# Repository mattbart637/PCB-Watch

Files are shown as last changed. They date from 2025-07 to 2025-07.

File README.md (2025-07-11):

# PCB Watch

<p style="text-align:center;">
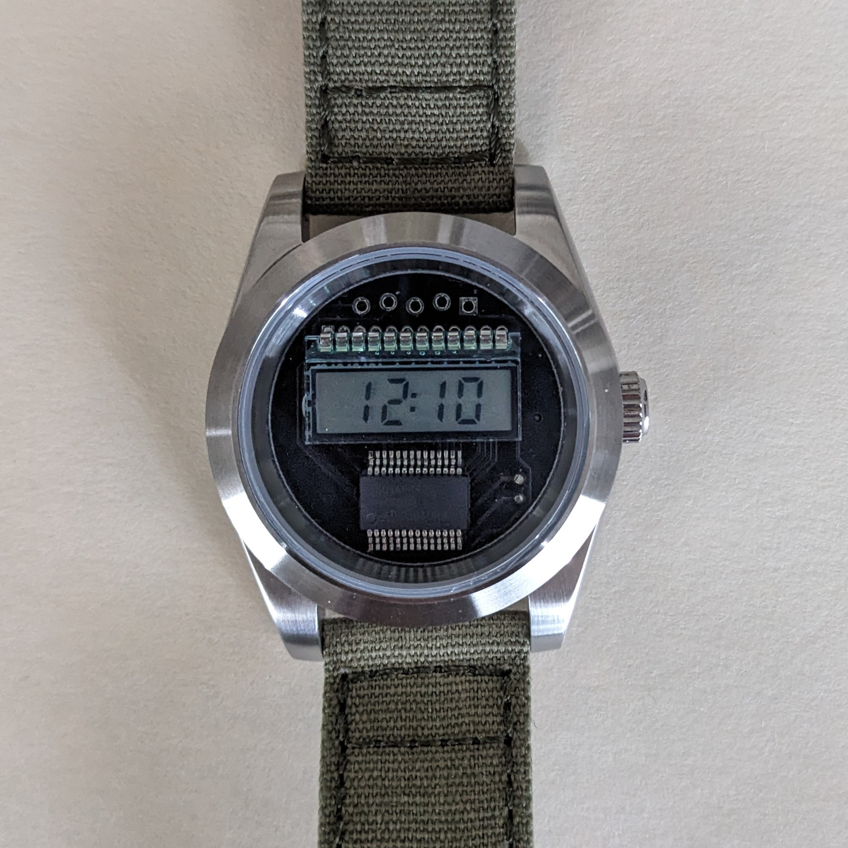
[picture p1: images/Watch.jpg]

</p>

A digital watch with a PIC16 and 4-digit segmented LCD display on a 2-layer PCB. It's my first microcontroller project outside the Arduino environment and the smallest SMT soldering I've done to date.

This build was heavily inspired by [Joe Sullivan's take](http://joesul.li/van/watch/) on a PIC16 watch. I loved finished look but didn't trust my soldering skills for the tiny hall-effect sensor or the daughter board it mounts on. Instead I simplified the interface to a single push-button. It makes the hardware simpler, but the firmware took a while to wrap my head around. 

I designed it for Seiko NH35 watch cases that accept 29mm dials, mostly because the NH35 has a strong modding community and there's plenty of aftermarket cases available. I got mine on AliExpress for under $20. A pair of 3D-printed spacers completes the build.

# Specs

| | |
| --- | --- |
| Dimensions | 29mm diameter, 7mm thick |
| Accuracy | 0.43 seconds/day, ~5 PPM |
| Current draw | 28.5µA @ 3V |
| Battery type | CR1220 |
| Runtime on 40mAh battery | ~58 days (estimate) |

# How to Use 

Once you insert a CR1220 battery it starts keeping time from 12:00.

1. Press and hold the button until Decimal Point 3 (DP3) lights up. Short press the button to change the minute.
2. Press and hold again and Decimal Point 1 (DP1) will light instead. Short press the button to change the hour.
3. Press and hold a final time until the decimal point turns off, setting the time.

<p style="text-align:center;">

</p>

# Photos

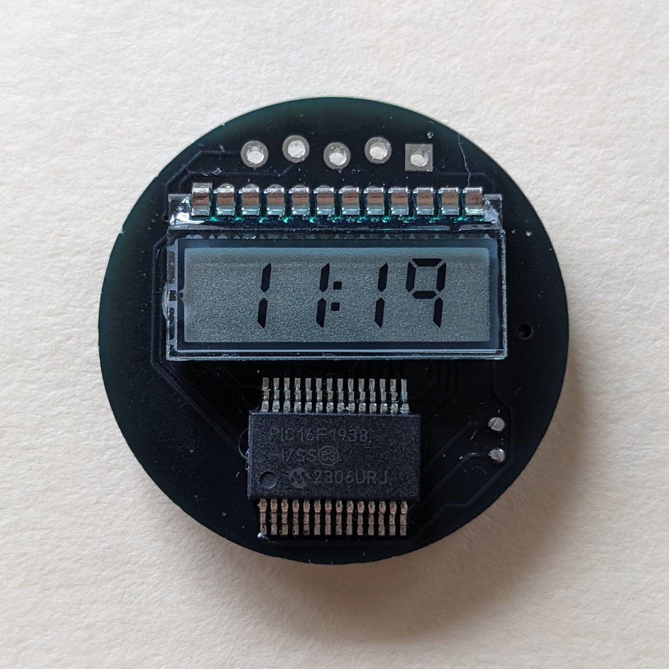
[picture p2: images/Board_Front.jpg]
Board front.
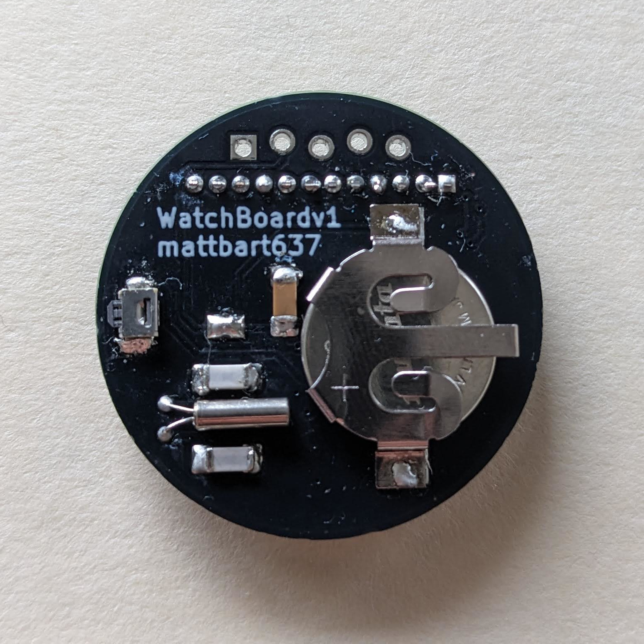
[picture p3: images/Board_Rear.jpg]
Board rear.


# Improvements for v2

My biggest gripe by far is with the 3D printed spacers, which work well but are tricky prints. I didn't include any anti-rotation features on the board, so instead the spacers have tiny pegs that sit in the programming header through holes. The parts aren't well suited to an FDM printer; mine were done on a DLP resin machine.

The spacer has a small tab that sticks into the crown opening to stop it rotating within the watch case. It works on the watch case I'm using (though not on all the ones I've tried) but blocks access to the button. That means disassembling the watch to set the time. Maybe not a huge deal since the battery life is only ~2 months, but I'd do it differently next time.

I want to make the spacers less demanding prints and include a keying tab on the board itself. I'd also swap the button with an edge-mount one (that sits in a recess on the board) to bring it more in line with the crown. Preferably one with a more tactile feel too.

Some other things I'd change:
- Add 24-Hour time support 
- I think there's room for reducing the current consumption and extending the battery life further.
- The manufacturer's footprint for the battery holder has the ground pad smaller than the battery diameter. On the next rev I'd make the pad larger than the battery diameter to get better contact. Otherwise you have to flood the pad with solder (making it higher than the surrounding soldermask) to make contact.

# Credits & References

Joe Sullivan's PIC16 watch: <http://joesul.li/van/watch/>

NH35 Specifications: <https://www.timemodule.com/uploads/attachments/download/Spec%20Sheet/NH35_SS.pdf>

It's not the same implementation or even the same microcontroller I used, but Microchip's Yet Another Clock Featuring the PIC16C924 application note was very helpful: <https://www.microchip.com/en-us/application-notes/an649>

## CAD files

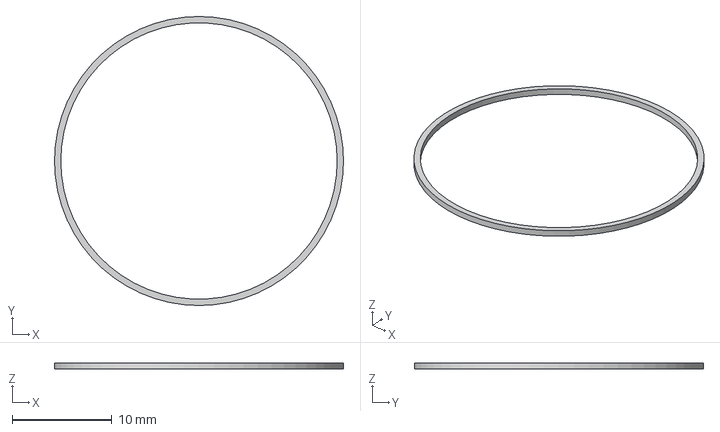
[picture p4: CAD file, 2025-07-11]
Spacers/STEP/DialSpacer.step
29.0 x 29.0 x 0.635 mm

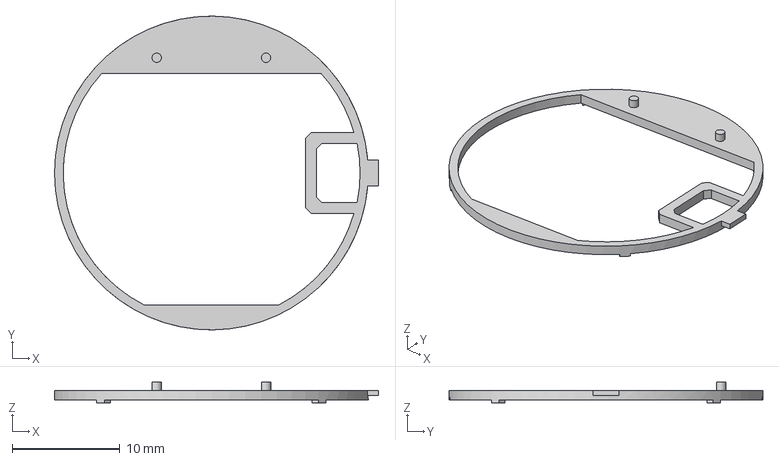
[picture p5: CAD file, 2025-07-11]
Spacers/STEP/BackSpacer.step
30.1 x 29.1 x 1.91 mm

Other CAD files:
Spacers/STL/BackSpacer.stl
Spacers/STL/DialSpacer.stl

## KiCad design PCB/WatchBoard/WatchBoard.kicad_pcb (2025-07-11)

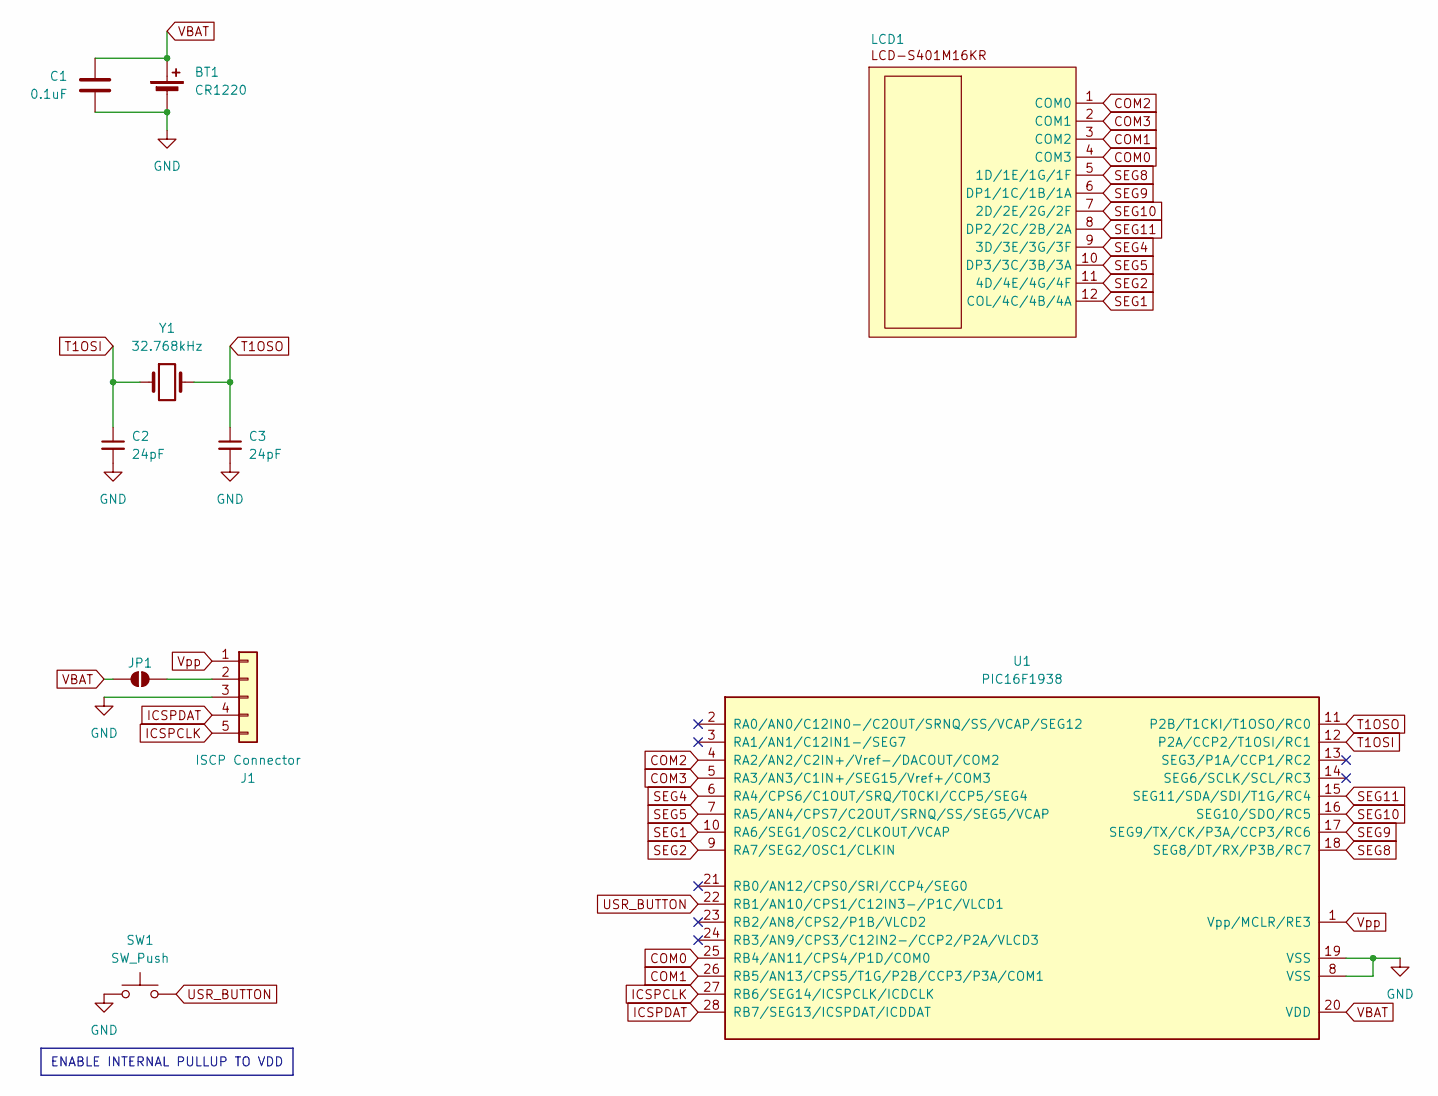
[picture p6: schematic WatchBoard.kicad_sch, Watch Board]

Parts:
BT1: CR1220; keystone_PN2894_BatteryHolder; Part_Number 2894
C1: 0.1uF; C_1206_3216Metric_Pad1.33x1.80mm_HandSolder; Part_Number C1206C104K5RACTU
C2, C3: 24pF; C_1206_3216Metric_Pad1.33x1.80mm_HandSolder; Part_Number C1206C240F1HACTU
J1: ISCP Connector; ISCPHeader_1x05_P2.54mm
JP1: SolderJumper-2_P1.3mm_Open_TrianglePad1.0x1.5mm
LCD1: LCD-S401M16KR; Part_Number LCD-S401M16KR
SW1: SW_Push; SW_B3U-3000P-B_OMR; Part_Number B3U-3000P-B
U1: PIC16F1938; PIC16F1938-X&slash_SS_MCH-L; Part_Number PIC16F1938T-I/SS
Y1: 32.768kHz; Crystal_CFS-206_D2.0mm_L6.2mm; Part_Number CFS-20632768HZFB

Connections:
COM0: LCD1.4 (COM3), U1.25 (RB4/AN11/CPS4/P1D/COM0)
COM1: LCD1.3 (COM2), U1.26 (RB5/AN13/CPS5/T1G/P2B/CCP3/P3A/COM1)
COM2: LCD1.1 (COM0), U1.4 (RA2/AN2/C2IN+/Vref-/DACOUT/COM2)
COM3: LCD1.2 (COM1), U1.5 (RA3/AN3/C1IN+/SEG15/Vref+/COM3)
GND: BT1.2 (-), C1.2, C2.2, C3.2, J1.3, SW1.2, U1.8 (VSS), U1.19 (VSS)
ICSPCLK: J1.5, U1.27 (RB6/SEG14/ICSPCLK/ICDCLK)
ICSPDAT: J1.4, U1.28 (RB7/SEG13/ICSPDAT/ICDDAT)
unnamed: J1.2, JP1.2 (B)
SEG1: LCD1.12 (COL/4C/4B/4A), U1.10 (RA6/SEG1/OSC2/CLKOUT/VCAP)
SEG2: LCD1.11 (4D/4E/4G/4F), U1.9 (RA7/SEG2/OSC1/CLKIN)
SEG4: LCD1.9 (3D/3E/3G/3F), U1.6 (RA4/CPS6/C1OUT/SRQ/T0CKI/CCP5/SEG4)
SEG5: LCD1.10 (DP3/3C/3B/3A), U1.7 (RA5/AN4/CPS7/C2OUT/SRNQ/SS/SEG5/VCAP)
SEG8: LCD1.5 (1D/1E/1G/1F), U1.18 (SEG8/DT/RX/P3B/RC7)
SEG9: LCD1.6 (DP1/1C/1B/1A), U1.17 (SEG9/TX/CK/P3A/CCP3/RC6)
SEG10: LCD1.7 (2D/2E/2G/2F), U1.16 (SEG10/SDO/RC5)
SEG11: LCD1.8 (DP2/2C/2B/2A), U1.15 (SEG11/SDA/SDI/T1G/RC4)
T1OSI: C2.1, U1.12 (P2A/CCP2/T1OSI/RC1), Y1.1
T1OSO: C3.1, U1.11 (P2B/T1CKI/T1OSO/RC0), Y1.2
USR_BUTTON: SW1.1, U1.22 (RB1/AN10/CPS1/C12IN3-/P1C/VLCD1)
VBAT: BT1.1 (+), C1.1, JP1.1 (A), U1.20 (VDD)
Vpp: J1.1, U1.1 (Vpp/MCLR/RE3)

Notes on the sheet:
ENABLE INTERNAL PULLUP TO VDD

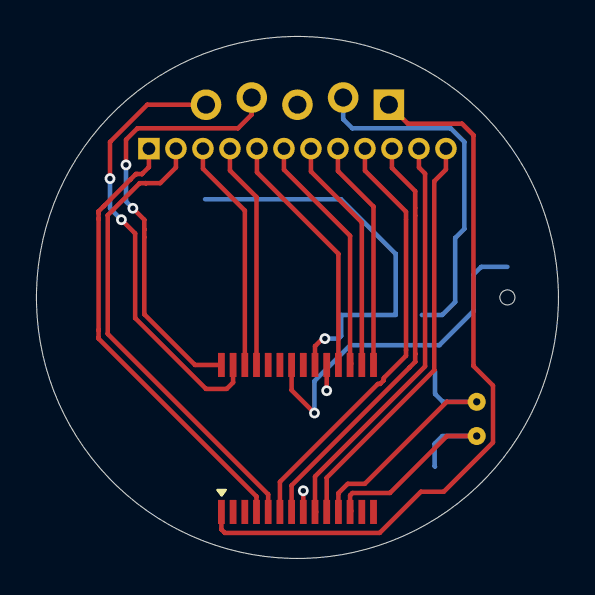
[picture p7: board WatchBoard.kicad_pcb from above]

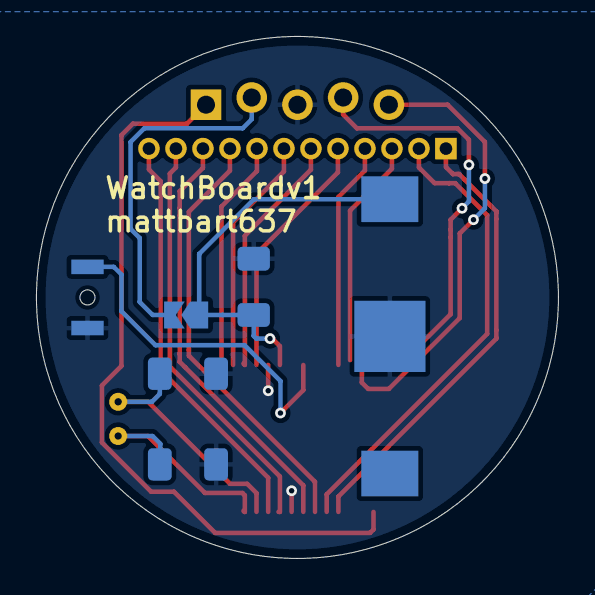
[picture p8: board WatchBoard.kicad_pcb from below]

Board: 2 copper layers, 29.0 x 29.0 mm, 10 parts (7 on the bottom side), 21 nets.

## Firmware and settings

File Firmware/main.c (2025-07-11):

/*
 * File:   main.c
 * 
 * Button logic:
 * Modes cycle from normal operation, setting minutes, setting hours. Press and hold 
 * for 3 seconds to cycle between modes. Decimal points illuminate to indicate
 * which mode you're in.
 * 
 * If in minute/hours setting mode, short press to advance minutes/hours.
 */

// PIC16F1938 Configuration Bit Settings

// 'C' source line config statements

// CONFIG1
#pragma config FOSC = INTOSC    // Oscillator Selection (INTOSC oscillator: I/O function on CLKIN pin)
#pragma config WDTE = OFF       // Watchdog Timer Enable (WDT disabled)
#pragma config PWRTE = OFF      // Power-up Timer Enable (PWRT disabled)
#pragma config MCLRE = ON       // MCLR Pin Function Select (MCLR/VPP pin function is MCLR)
#pragma config CP = OFF         // Flash Program Memory Code Protection (Program memory code protection is disabled)
#pragma config CPD = OFF        // Data Memory Code Protection (Data memory code protection is disabled)
#pragma config BOREN = ON       // Brown-out Reset Enable (Brown-out Reset enabled)
#pragma config CLKOUTEN = OFF   // Clock Out Enable (CLKOUT function is disabled. I/O or oscillator function on the CLKOUT pin)
#pragma config IESO = ON        // Internal/External Switchover (Internal/External Switchover mode is enabled)
#pragma config FCMEN = ON       // Fail-Safe Clock Monitor Enable (Fail-Safe Clock Monitor is enabled)

// CONFIG2
#pragma config WRT = OFF        // Flash Memory Self-Write Protection (Write protection off)
#pragma config VCAPEN = OFF     // Voltage Regulator Capacitor Enable (All VCAP pin functionality is disabled)
#pragma config PLLEN = OFF      // PLL Enable (4x PLL disabled)
#pragma config STVREN = ON      // Stack Overflow/Underflow Reset Enable (Stack Overflow or Underflow will cause a Reset)
#pragma config BORV = LO        // Brown-out Reset Voltage Selection (Brown-out Reset Voltage (Vbor), low trip point selected.)
#pragma config LVP = ON         // Low-Voltage Programming Enable (Low-voltage programming enabled)

// #pragma config statements should precede project file includes.
// Use project enums instead of #define for ON and OFF.

#define _XTAL_FREQ 500000
int D1 = 1;         // LCD digit 1 value
int D2 = 2;         // LCD digit 2 value
int D3 = 0;         // LCD digit 3 value
int D4 = 0;         // LCD digit 4 value
int DP1 = 0;        // Decimal Point 1 On/Off
int DP3 = 0;        // Decimal Point 3 On/Off
int seconds = 0;
int minutes = 0;
int hours = 12;
int set_mode = 0;       // 0 = timekeeping, 1 = set min, 2 = set hr
int long_press = 0;     // flag for when a long press (2s) is detected
int button_state = 1;   // capture button state, 0 is pressed
int tick = 0;           // temp variable used to count entrance into time setting mode

#include <xc.h>
#include <stdio.h>
#include <stdlib.h>
#include "lcd.h"
#include "button.h"

void main(void) 
{
    // Button configuration
    TRISBbits.TRISB1 = 1;       // RB1 input
    ANSELBbits.ANSB1 = 0;       // RB1 digital
    OPTION_REGbits.nWPUEN = 0;  // Weak pull-ups are enabled by individual WPUx latch values
    WPUBbits.WPUB1 = 1;         // RB1 pullup enabled
    
    // Timer1 configuration
    T1CONbits.nT1SYNC = 1;      //Do not synchronize with system clock
    T1CONbits.T1CKPS0 = 0;      //1:1 prescale value 
    T1CONbits.T1CKPS1 = 0;
    T1CONbits.TMR1CS = 2;       //set oscillator as Timer1 source
    
    // Enable Timer1 count
    T1CONbits.TMR1ON = 1;       //enable Timer1
    T1GCONbits.TMR1GE = 1;      //enable Timer1 gate
    
    // Enable oscillator circuit with delay for startup time
    T1CONbits.T1OSCEN = 1;      //enable oscillator circuit
    PIR1bits.TMR1IF = 0;        //clear interrupt flag
    TMR1L = 0x00;
    TMR1H = 0xfc;
    
    // Interrupt configuration
    INTCONbits.GIE = 1;         // Global Interrupt Enable
    INTCONbits.PEIE = 1;        // Peripheral Interrupt Enable
    INTCONbits.IOCIE = 1;       // Interrupt-on-change enable
    PIE1bits.TMR1IE = 1;        // Timer1 Interrupt Enable
   
    // Turn on display
    initializeLCD();
    updateLCD();
    
    while(1)
    {        
        if (seconds == 60) 
        {
            seconds = 0; 
            minutes++; 
            if (minutes == 60) 
            {
               minutes = 0;
               hours++;
               if (hours == 13) 
               {
                   hours = 1;
               }
            }
            digitsHM_LCD();
            updateLCD();
        }

        switch(set_mode)
        {
            case 0:
                if (PORTBbits.RB1 == 0) {tick++;}
                else {tick = 0;}
                if (tick == 3)
                {
                    PIE1bits.TMR1IE = 0;
                    PIR1bits.TMR1IF = 0; // Clear Timer1 interrupt flag in PIR1 register
                    tick = 0; 
                    DP3 = 1;
                    DP1 = 0;
                    set_mode = 1; 
                    updateLCD();
                    wait_release();
                }
                else {SLEEP();}
                break;
            case 1:
                if (PORTBbits.RB1 == 0 && button_state == 1)
                {
                    button_pressed();
                }                    
                if (PORTBbits.RB1 == 1 && button_state == 0)
                {
                    button_released();
                    minutes++; if (minutes == 60) {minutes = 0;}
                    digitsHM_LCD();
                    updateLCD();
                }
                if (long_press == 1)
                {
                    long_press = 0;
                    set_mode = 2;
                    DP3 = 0;
                    DP1 = 1;
                    updateLCD();
                    wait_release();
                }
                break;
            case 2:
                if (PORTBbits.RB1 == 0 && button_state == 1) // pressed
                {
                    button_pressed();
                }    
                if (PORTBbits.RB1 == 1 && button_state == 0)   // released
                {
                    button_released();
                    hours++; if (hours == 13) {hours = 1;}
                    digitsHM_LCD();
                    updateLCD();
                }
                if (long_press == 1)
                {
                    long_press = 0;
                    set_mode = 0;
                    seconds = 0;
                    DP3 = 0;
                    DP1 = 0;
                    updateLCD();
                    TMR1L = 0;
                    TMR1H = 0b10000000;
                    PIR1bits.TMR1IF = 0;
                    PIE1bits.TMR1IE = 1;                    
                    wait_release();
                }
                break;
        }
    }
}

// Interrupt service routine
void __interrupt() isr()
{
    // 1 Second elapsed under normal timekeeping
    if (PIR1bits.TMR1IF == 1 && set_mode == 0)
    {
        seconds++;
        PIR1bits.TMR1IF = 0; // Clear Timer1 interrupt flag in PIR1 register
        TMR1H |= 0b10000000;       // Overflow 1 second later)
    }
    
    
    // Long-press timer expires
    if (PIR1bits.TMR1IF == 1 && set_mode != 0)
    {
        PIE1bits.TMR1IE = 0; // Disable interrupt, will be re-enabled in main loop
        PIR1bits.TMR1IF = 0; // Clear Timer1 interrupt flag in PIR1 register
        long_press = 1;
    }
}
